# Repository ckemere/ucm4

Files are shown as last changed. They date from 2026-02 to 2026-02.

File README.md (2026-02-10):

# CM4-uSAW

Raspberry Pi Compute Module 4 micro carrier board with a multimodal Sensor Array and Wireless (uSAW) battery operation.

# Features

- Dual-camera inputs
- 9-axis IMU
- Stereo microphones
- GNSS module header (ZED GNSS)
- Stemma/QUIIC connector
- Power management
  - Battery charging & discharging
  - Fuel gauge
  - USB-C or L-ion power source
- SD card carrier
- UART Extension pins
- support for both Lite and eMMC variants of CM4
- USB C for power and USB 2.0 data transfer
- USB-OTG support

# Table of contents

1. [Sensors](sensors.md)

# License

This work is licensed under a [Creative Commons Attribution 4.0 International License][cc-by].

You can use it for anything as long as you preserve license file and author information in source distribution and authorship information on PCB. Derived work should mention original author in same locations as this repository.

[][cc-by]

[cc-by]: http://creativecommons.org/licenses/by/4.0/
[cc-by-image]: https://i.creativecommons.org/l/by/4.0/88x31.png

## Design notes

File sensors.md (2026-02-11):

## Cameras
Dual camera inputs on cam1 and cam0 lines.

### config.txt example:
# Disable auto-detect if you are forcing manual overlays
camera_auto_detect=0

# Define camera on Port 0
dtoverlay=imx708,cam0
# Define camera on Port 1
dtoverlay=imx708,cam1

## Stereo Microphone
Dual/stereo audio inputs on left and right edges of board.
MMICT390200012, converted from PDM to PCM.

### config.txt example:
dtoverlay=googlevoicehat-soundcard

## IMU
Bosh BNO055 9 axis IMU
UART channel 5

### config.txt example:
dtoverlay=uart5

## Fuel Gauge
MAX17048G+ smart battery fuel gauge.

# Enable I2C-3 for Fuel Gauge
dtoverlay=i2c3,pins_2_3

## GPS

### config.txt example:
dtoverlay=uart4

GPS UART4 connection seems to interfere with booting.

Fix:

Edit
/boot/firmware/cmdline.txt

The Edit:

    Find: A section of text looking like console=serial0,115200 (or console=ttyAMA0,115200).

    Action: Delete that specific section.

    Keep: Everything else (like root=..., console=tty1, fsck...).

Ensure cmdline.txt remains one single line of text. Do not add line breaks or newlines.

## All required configs (untested)

camera_auto_detect=0
dtoverlay=imx708,cam0
dtoverlay=imx708,cam1
dtoverlay=googlevoicehat-soundcard
dtoverlay=uart5
dtoverlay=i2c3,pins_2_3

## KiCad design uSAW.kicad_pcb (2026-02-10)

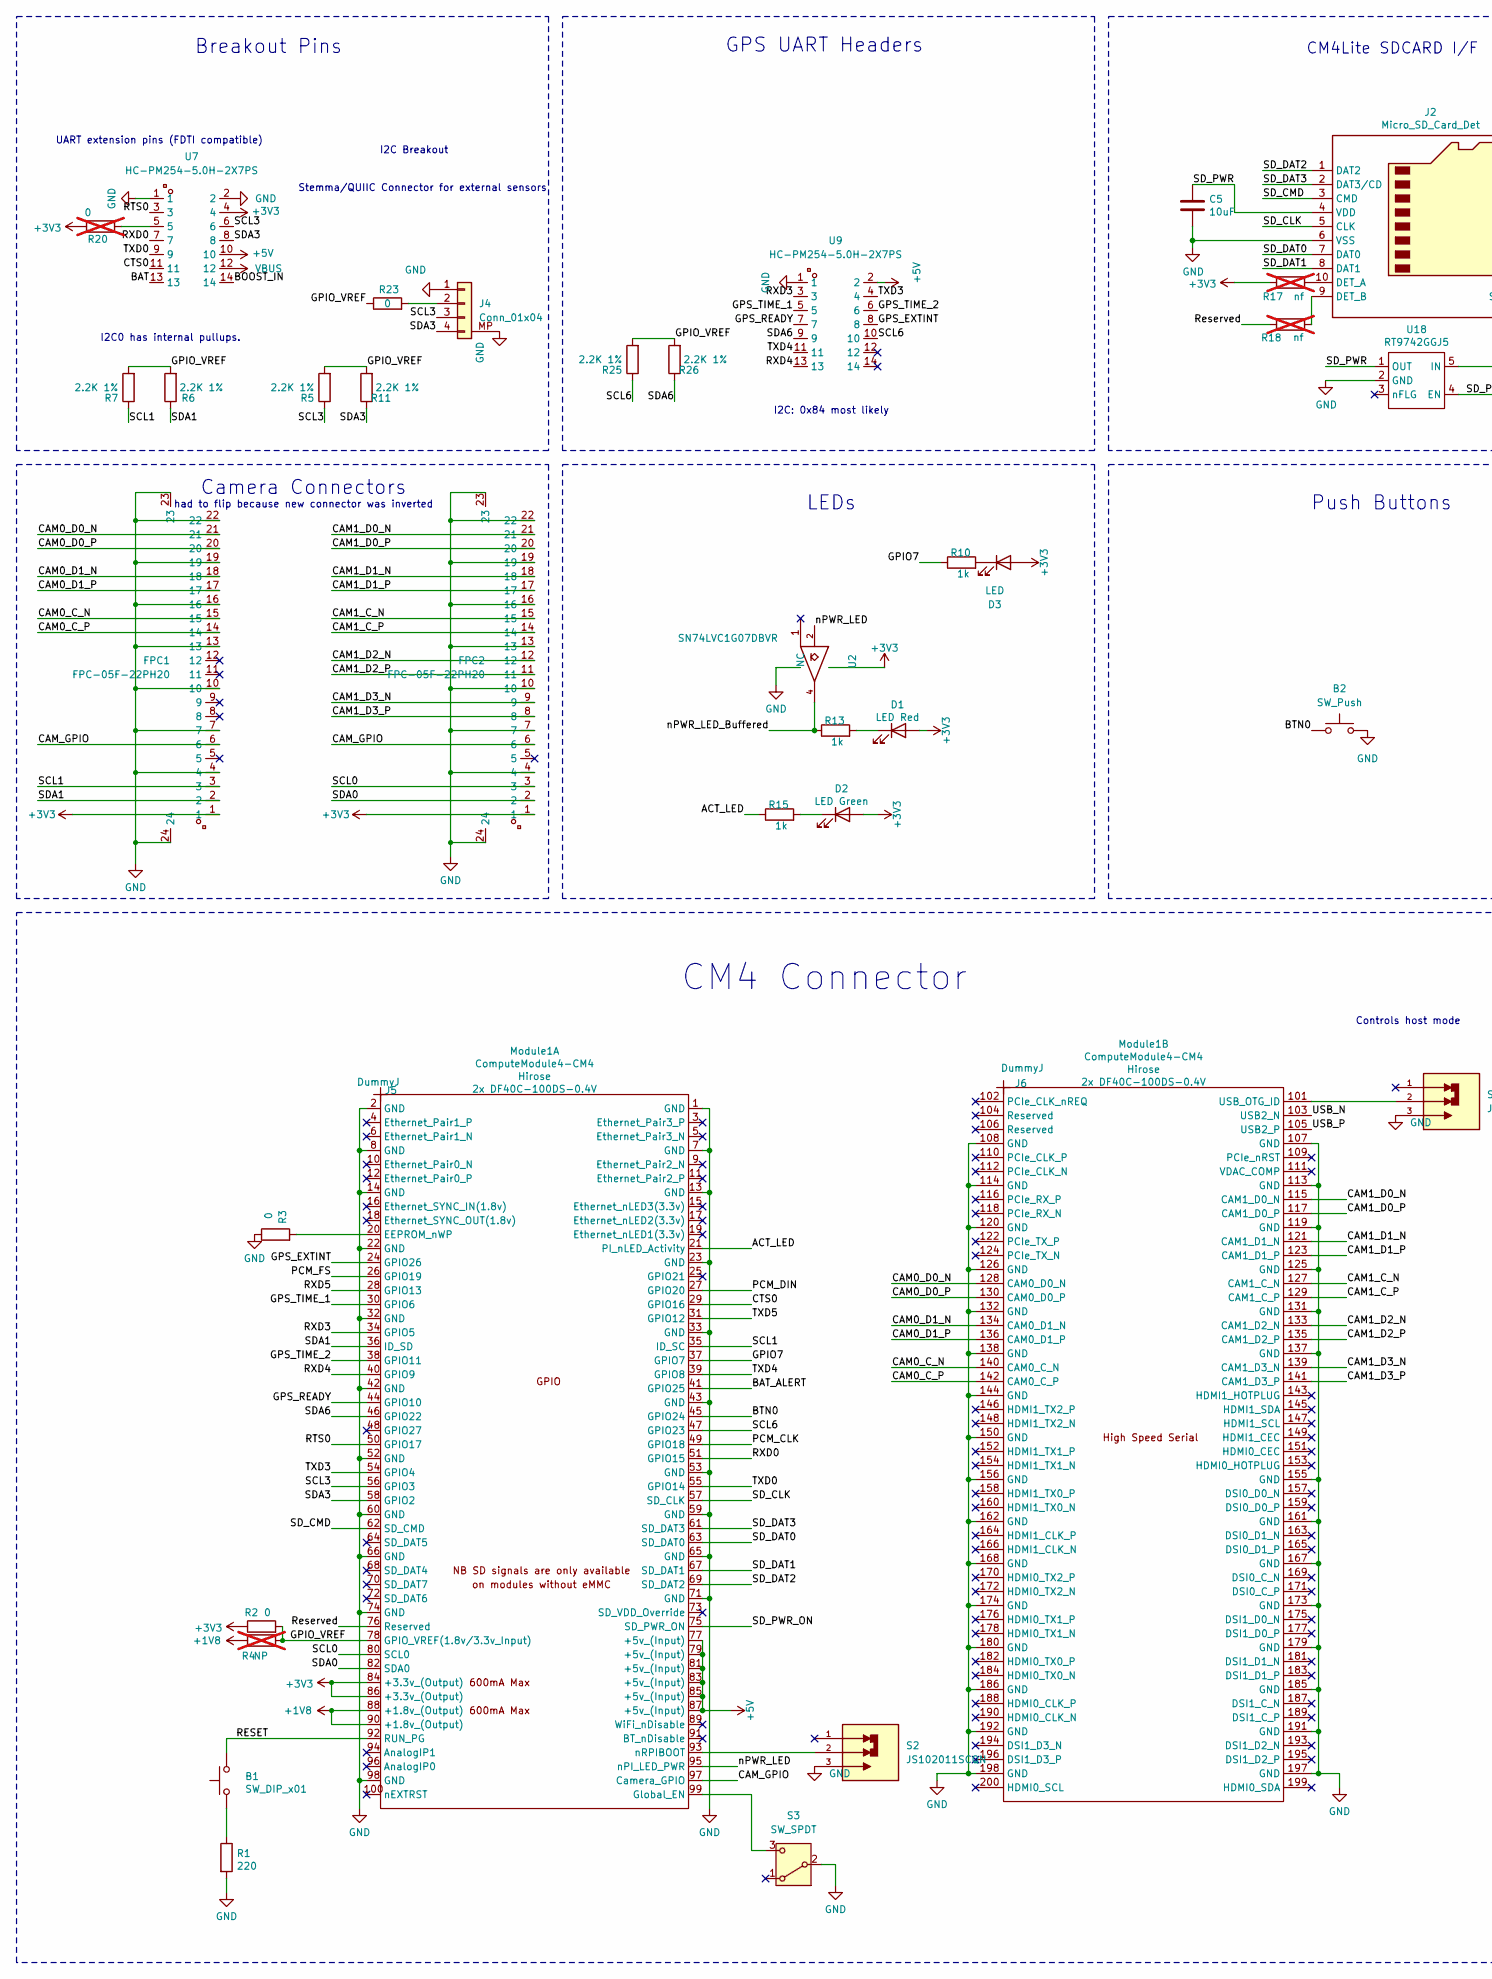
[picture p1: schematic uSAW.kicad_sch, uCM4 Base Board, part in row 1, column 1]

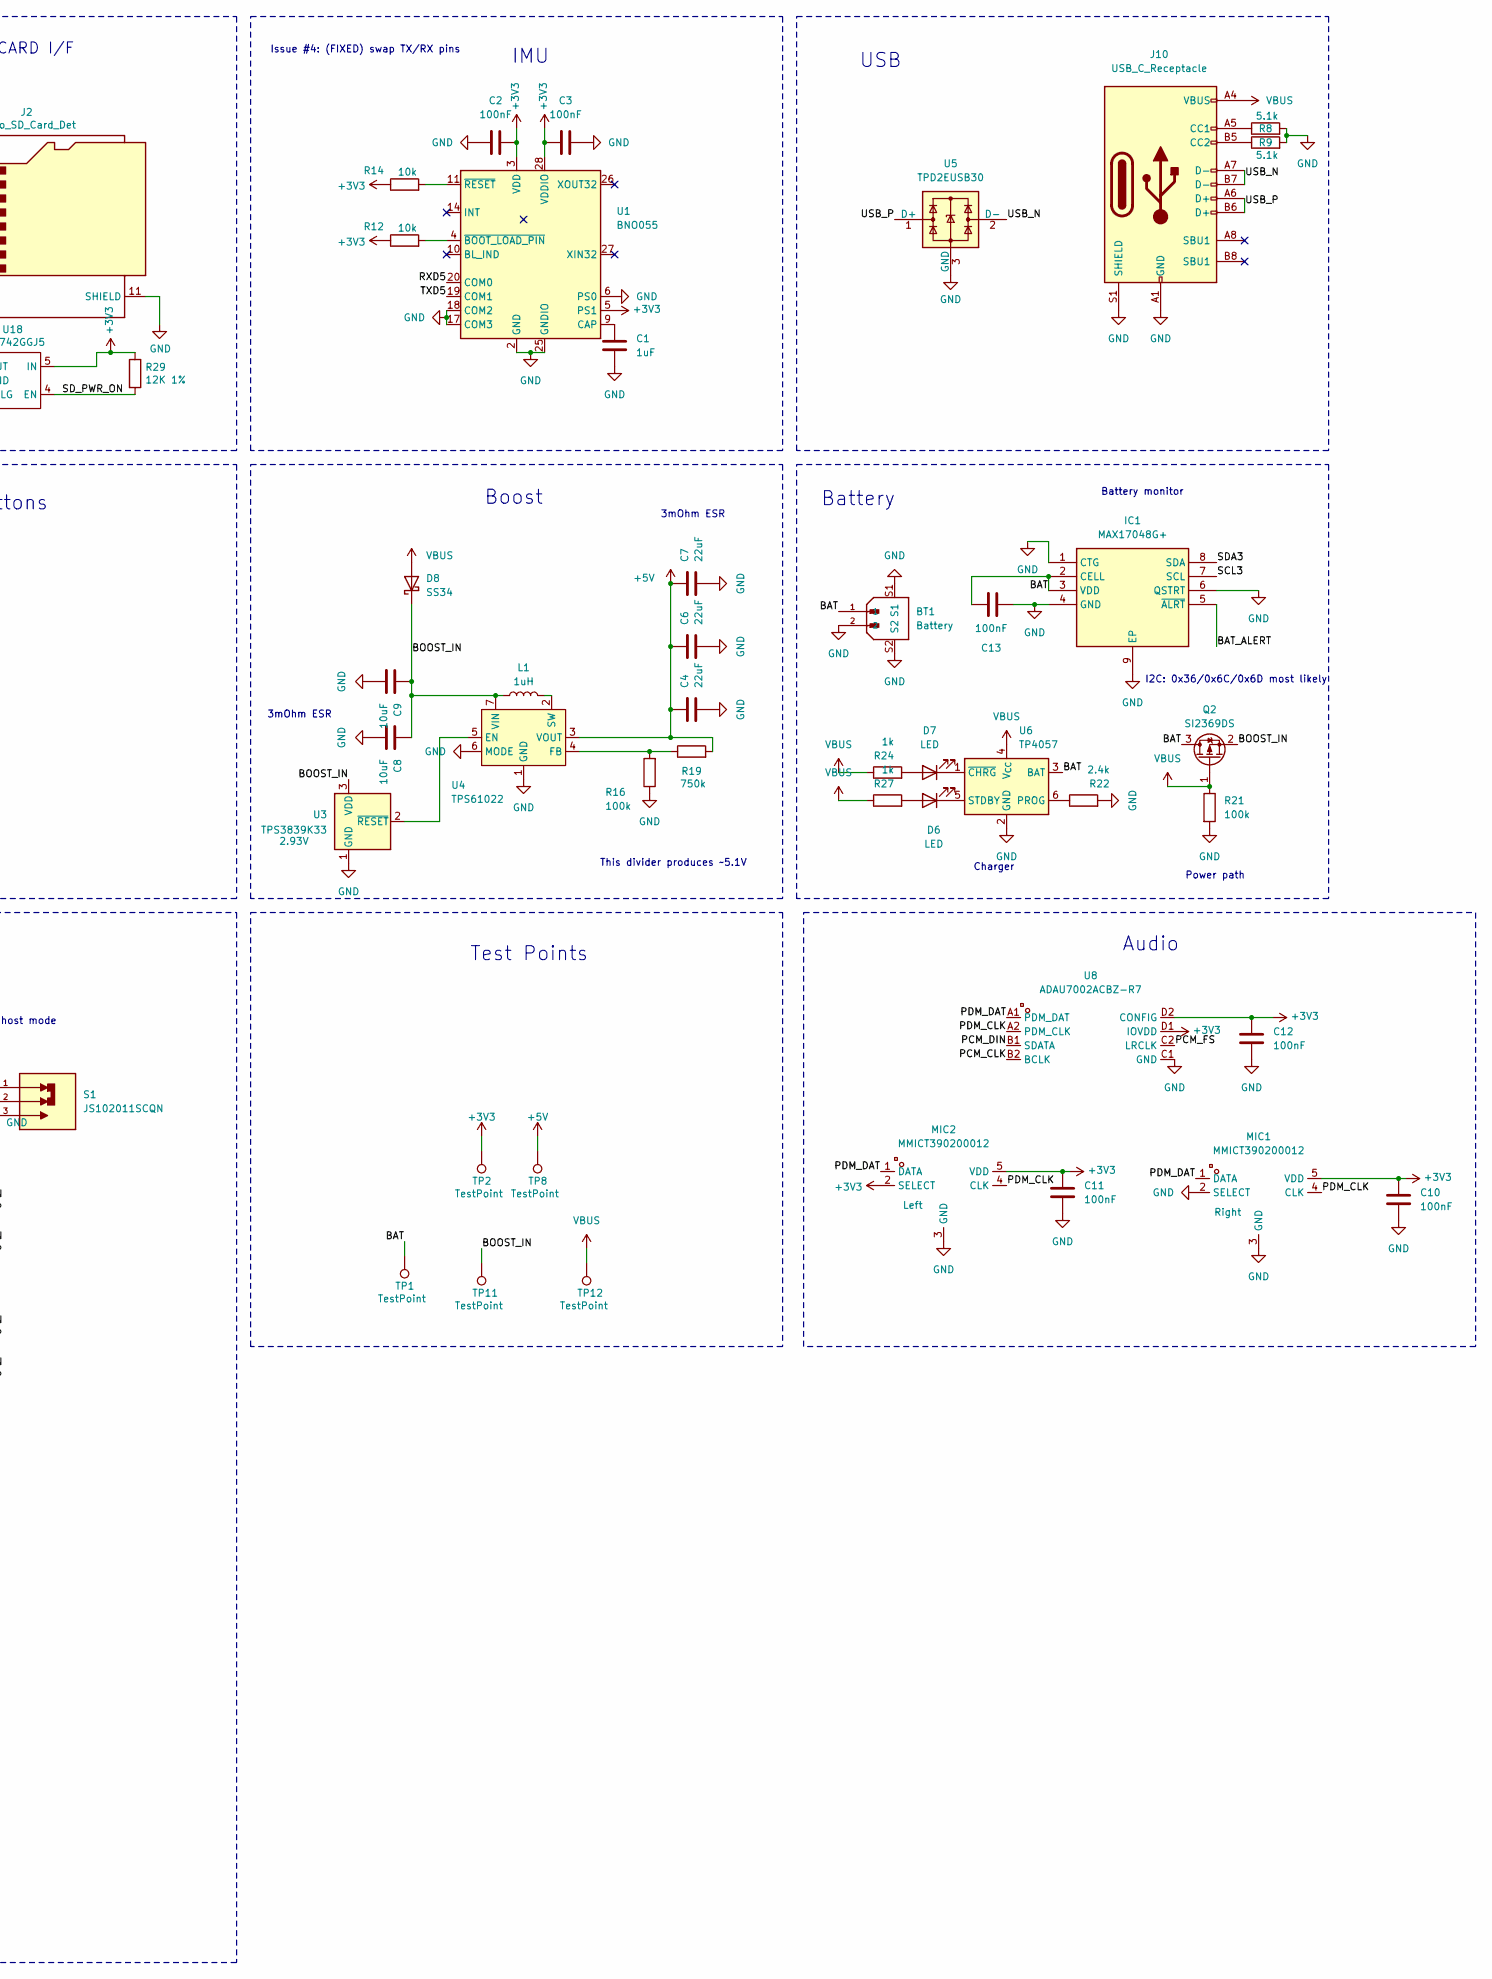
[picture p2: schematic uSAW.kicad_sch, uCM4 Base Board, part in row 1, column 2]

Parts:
B1: SW_DIP_x01; PTS840_PM_SMTR_LFS; LCSC Part # C221907
B2: SW_Push; PTS840_PM_SMTR_LFS; LCSC Part # C221907
BT1: Battery; JST_B2B-PH-SM4-TB; PARTREV N/A; LCSC Part # C2763702
C1: 1uF; C_0402_1005Metric; LCSC Part # C14445
C2, C3, C10, C11, C12, C13: 100nF; C_0402_1005Metric; LCSC Part # C1525
C4, C6, C7: 22uF; C_1206_3216Metric; LCSC Part # C12891
C5: 10uF; C_0603_1608Metric; Part Description 10uF 10% 10V Ceramic Capacitor X7R 0805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; LCSC Part # C19702
C8, C9: 10uF; C_0603_1608Metric; LCSC Part # C19702
D1: LED Red; LED_0402_1005Metric; LCSC Part # C264407
D2: LED Green; LED_0402_1005Metric; LCSC Part # C5123485
D3, D6: LED; LED_0402_1005Metric; LCSC Part # C5123485
D7: LED; LED_0402_1005Metric; LCSC Part # C264407
D8: SS34; D_SMA; LCSC Part # C727059
FPC1, FPC2: FPC-05F-22PH20; FPC-SMD_22P-P0.50_FPC-05F-22PH20; LCSC Part C2856804
IC1: MAX17048G+; SON50P200X200X80-9N-D; Manufacturer_Part_Number MAX17048G+; Mouser Part Number 700-MAX17048G+
J2: Micro_SD_Card_Det; SDCARD_MOLEX_503398-1892; Part Description 9 (8 + 1) Position Card Connector micro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; LCSC Part # C428492
J4: Conn_01x04; JST_SH_BM04B-SRSS-TB_1x04-1MP_P1.00mm_Vertical; LCSC Part # C160390
J5, J6: DummyJ; LCSC Part # C597931
J10: USB_C_Receptacle; USB_C_Receptacle_GCT_USB4105-xx-A_16P_TopMnt_Horizontal; LCSC C5184243
L1: 1uH; XAL7030102MEC; Part# XAL7030-102MEC; LCSC Part # C19191626
MIC1, MIC2: MMICT390200012; MIC-SMD_5P-L3.5-W2.7-TL_MMICT390200012; LCSC Part C3171752
Module1: ComputeModule4-CM4; Raspberry-Pi-4-Compute-Module; LCSC Part # C597931
Q2: SI2369DS; SOT-23; LCSC Part # C41348108
R1: 220; R_0603_1608Metric_Pad0.98x0.95mm_HandSolder; LCSC Part # C22962
R2, R3, R23: 0; R_0402_1005Metric; LCSC Part # C106231
R4: NP; R_0402_1005Metric; LCSC Part # C106231; not fitted
R5, R6, R7, R11, R25, R26: 2.2K 1%; R_0402_1005Metric; Part Description Resistor 2.2K M1005 1% 63mW; LCSC Part # C60488
R8, R9: 5.1k; R_0402_1005Metric; LCSC Part # C25905
R10, R13, R15, R24, R27: 1k; R_0402_1005Metric; LCSC Part # C106235
R12, R14: 10k; R_0402_1005Metric; LCSC Part # C60490
R16, R21: 100k; R_0402_1005Metric; LCSC Part # C852472
R17, R18: nf; R_0402_1005Metric; Part Description Resistor 1K M1005 1% 63mW; not fitted
R19: 750k; R_0402_1005Metric; LCSC Part # C2909381
R20: 0; R_0402_1005Metric; LCSC Part # C21189; not fitted
R22: 2.4k; R_0402_1005Metric; LCSC Part # C25882
R29: 12K 1%; R_0402_1005Metric; Part Description Resistor 12K M1005 1% 63mW; LCSC Part # C25752
S1, S2: JS102011SCQN; SW_JS102011SCQN; PARTREV 8 Oct 21; LCSC Part # C221661
S3: SW_SPDT; SW_SPDT_PCM12; LCSC Part # C221841
TP1, TP2, TP8, TP11, TP12: TestPoint; TestPoint_Pad_D1.0mm
U1: BNO055; LGA-28_5.2x3.8mm_P0.5mm; LCSC Part # C93216
U2: SN74LVC1G07DBVR; SOT-23-5_HandSoldering; LCSC Part # C7829
U3: TPS3839DBZ; SOT-23; Threshold voltage 2.93V; Part_Code TPS3839K33; LCSC Part # C96333
U4: TPS61022; Texas_RWU0007A_VQFN-7_2x2mm_P0.5mm; LCSC Part # C915088
U5: TPD2EUSB30; Texas_DRT-3; LCSC Part # C3040102
U6: TP4057; TSOT-23-6; LCSC Part # C725791
U7, U9: HC-PM254-5.0H-2X7PS; HDR-SMD_14P-P2.54-V-F-R2-C7-LS7.4; LCSC Part # C42163135
U8: ADAU7002ACBZ-R7; WLCSP-8_L1.6-W0.8-R2-C4-P0.40-TL; LCSC Part C481886
U18: RT9742GGJ5; SOT-23-5; Part Description Power Switch/Driver 1:1 N-Channel 1A TS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; LCSC Part # C250547

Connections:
+1V8: Module1.88 (+1.8v_(Output)), Module1.90 (+1.8v_(Output)), R4.1
+3V3: C2.2, C3.2, C10.1, C11.1, C12.1, D1.2 (A), D2.2 (A), D3.2 (A), FPC1.1, FPC2.1, MIC1.5 (VDD), MIC2.2 (SELECT), MIC2.5 (VDD), Module1.84 (+3.3v_(Output)), Module1.86 (+3.3v_(Output)), R2.1, R12.1, R14.1, R17.1, R20.1, R29.1, TP2.1, U1.3 (VDD), U1.5 (PS1), U1.28 (VDDIO), U2.5 (VCC), U7.4, U8.D1 (IOVDD), U8.D2 (CONFIG), U18.5 (IN)
+5V: C4.1, C6.1, C7.1, Module1.77 (+5v_(Input)), Module1.79 (+5v_(Input)), Module1.81 (+5v_(Input)), Module1.83 (+5v_(Input)), Module1.85 (+5v_(Input)), Module1.87 (+5v_(Input)), R19.2, TP8.1, U4.3 (VOUT), U7.10, U9.2
/ACT_LED: Module1.21 (PI_nLED_Activity), R15.1
/BAT: BT1.1, C13.1, IC1.2 (CELL), IC1.3 (VDD), Q2.3 (D), TP1.1, U6.3 (BAT), U7.13
/BAT_ALERT: IC1.5 (~ALRT), Module1.41 (GPIO25)
/BOOST_IN: C8.1, C9.1, D8.1 (K), L1.1, Q2.2 (S), TP11.1, U3.3 (VDD), U4.7 (VIN), U7.14
/BTN0: B2.1, Module1.45 (GPIO24)
/CAM0_C_N: FPC1.15, Module1.140 (CAM0_C_N)
/CAM0_C_P: FPC1.14, Module1.142 (CAM0_C_P)
/CAM0_D0_N: FPC1.21, Module1.128 (CAM0_D0_N)
/CAM0_D0_P: FPC1.20, Module1.130 (CAM0_D0_P)
/CAM0_D1_N: FPC1.18, Module1.134 (CAM0_D1_N)
/CAM0_D1_P: FPC1.17, Module1.136 (CAM0_D1_P)
/CAM1_C_N: FPC2.15, Module1.127 (CAM1_C_N)
/CAM1_C_P: FPC2.14, Module1.129 (CAM1_C_P)
/CAM1_D0_N: FPC2.21, Module1.115 (CAM1_D0_N)
/CAM1_D0_P: FPC2.20, Module1.117 (CAM1_D0_P)
/CAM1_D1_N: FPC2.18, Module1.121 (CAM1_D1_N)
/CAM1_D1_P: FPC2.17, Module1.123 (CAM1_D1_P)
/CAM1_D2_N: FPC2.12, Module1.133 (CAM1_D2_N)
/CAM1_D2_P: FPC2.11, Module1.135 (CAM1_D2_P)
/CAM1_D3_N: FPC2.9, Module1.139 (CAM1_D3_N)
/CAM1_D3_P: FPC2.8, Module1.141 (CAM1_D3_P)
/CAM_GPIO: FPC1.6, FPC2.6, Module1.97 (Camera_GPIO)
/CTS0: Module1.29 (GPIO16), U7.11
/GPIO7: Module1.37 (GPIO7), R10.1
/GPIO_VREF: Module1.78 (GPIO_VREF(1.8v/3.3v_Input)), R2.2, R4.2, R5.2, R6.2, R7.2, R11.2, R23.1, R25.2, R26.2
/GPS_EXTINT: Module1.24 (GPIO26), U9.8
/GPS_READY: Module1.44 (GPIO10), U9.7
/GPS_TIME_1: Module1.30 (GPIO6), U9.5
/GPS_TIME_2: Module1.38 (GPIO11), U9.6
/PCM_CLK: Module1.49 (GPIO18), U8.B2 (BCLK)
/PCM_DIN: Module1.27 (GPIO20), U8.B1 (SDATA)
/PCM_FS: Module1.26 (GPIO19), U8.C2 (LRCLK)
/PDM_CLK: MIC1.4 (CLK), MIC2.4 (CLK), U8.A2 (PDM_CLK)
/PDM_DAT: MIC1.1 (DATA), MIC2.1 (DATA), U8.A1 (PDM_DAT)
/RESET: B1.2, Module1.92 (RUN_PG)
/RTS0: Module1.50 (GPIO17), U7.3
/RXD0: Module1.51 (GPIO15), U7.7
/RXD3: Module1.34 (GPIO5), U9.3
/RXD4: Module1.40 (GPIO9), U9.13
/RXD5: Module1.28 (GPIO13), U1.20 (COM0)
/Reserved: Module1.76 (Reserved), R18.1
/SCL0: FPC2.3, Module1.80 (SCL0)
/SCL1: FPC1.3, Module1.35 (ID_SC), R7.1
/SCL3: IC1.7 (SCL), J4.3, Module1.56 (GPIO3), R5.1, U7.6
/SCL6: Module1.47 (GPIO23), R25.1, U9.10
/SDA0: FPC2.2, Module1.82 (SDA0)
/SDA1: FPC1.2, Module1.36 (ID_SD), R6.1
/SDA3: IC1.8 (SDA), J4.4, Module1.58 (GPIO2), R11.1, U7.8
/SDA6: Module1.46 (GPIO22), R26.1, U9.9
/SD_CLK: J2.5 (CLK), Module1.57 (SD_CLK)
/SD_CMD: J2.3 (CMD), Module1.62 (SD_CMD)
/SD_DAT0: J2.7 (DAT0), Module1.63 (SD_DAT0)
/SD_DAT1: J2.8 (DAT1), Module1.67 (SD_DAT1)
/SD_DAT2: J2.1 (DAT2), Module1.69 (SD_DAT2)
/SD_DAT3: J2.2 (DAT3/CD), Module1.61 (SD_DAT3)
/SD_PWR: C5.1, J2.4 (VDD), U18.1 (OUT)
/SD_PWR_ON: Module1.75 (SD_PWR_ON), R29.2, U18.4 (EN)
/TXD0: Module1.55 (GPIO14), U7.9
/TXD3: Module1.54 (GPIO4), U9.4
/TXD4: Module1.39 (GPIO8), U9.11
/TXD5: Module1.31 (GPIO12), U1.19 (COM1)
/USB_N: J10.A7 (D-), J10.B7 (D-), Module1.103 (USB2_N), U5.2 (D-)
/USB_P: J10.A6 (D+), J10.B6 (D+), Module1.105 (USB2_P), U5.1 (D+)
/nPWR_LED: Module1.95 (nPI_LED_PWR), U2.2
/nPWR_LED_Buffered: R13.1, U2.4
GND: B2.2, BT1.2, BT1.S1, BT1.S2, C1.1, C2.1, C3.1, C4.2, C5.2, C6.2, C7.2, C8.2, C9.2, C10.2, C11.2, C12.2, C13.2, FPC1.4, FPC1.7, FPC1.10, FPC1.13, FPC1.16, FPC1.19, FPC1.22, FPC1.23, FPC1.24, FPC2.4, FPC2.7, FPC2.10, FPC2.13, FPC2.16, FPC2.19, FPC2.22, FPC2.23, FPC2.24, IC1.1 (CTG), IC1.4 (GND), IC1.6 (QSTRT), IC1.9 (EP), J2.6 (VSS), J2.11 (SHIELD), J4.1, J4.MP, J10.A1 (GND), J10.A12 (GND), J10.B1 (GND), J10.B12 (GND), J10.S1 (SHIELD), MIC1.2 (SELECT), MIC1.3 (GND), MIC2.3 (GND), Module1.1 (GND), Module1.2 (GND), Module1.7 (GND), Module1.8 (GND), Module1.13 (GND), Module1.14 (GND), Module1.22 (GND), Module1.23 (GND), Module1.32 (GND), Module1.33 (GND), Module1.42 (GND), Module1.43 (GND), Module1.52 (GND), Module1.53 (GND), Module1.59 (GND), Module1.60 (GND), Module1.65 (GND), Module1.66 (GND), Module1.71 (GND), Module1.74 (GND), Module1.98 (GND), Module1.107 (GND), Module1.108 (GND), Module1.113 (GND), Module1.114 (GND), Module1.119 (GND), Module1.120 (GND), Module1.125 (GND), Module1.126 (GND), Module1.131 (GND), Module1.132 (GND), Module1.137 (GND), Module1.138 (GND), Module1.144 (GND), Module1.150 (GND), Module1.155 (GND), Module1.156 (GND), Module1.161 (GND), Module1.162 (GND), Module1.167 (GND), Module1.168 (GND), Module1.173 (GND), Module1.174 (GND), Module1.179 (GND), Module1.180 (GND), Module1.185 (GND), Module1.186 (GND), Module1.191 (GND), Module1.192 (GND), Module1.197 (GND), Module1.198 (GND), R1.2, R3.1, R8.2, R9.2, R16.1, R21.2, R22.2, S1.3, S2.3, S3.2 (B), U1.2 (GND), U1.6 (PS0), U1.17 (COM3), U1.18 (COM2), U1.25 (GNDIO), U2.3 (GND), U3.1 (GND), U4.1 (GND), U4.6 (MODE), U5.3 (GND), U6.2 (GND), U7.1, U7.2, U8.C1 (GND), U9.1, U18.2 (GND)
unnamed: B1.1, R1.1
unnamed: D1.1 (K), R13.2
unnamed: D2.1 (K), R15.2
unnamed: D3.1 (K), R10.2
unnamed: D6.2 (A), R27.2
unnamed: D6.1 (K), U6.5 (STDBY)
unnamed: D7.2 (A), R24.2
unnamed: D7.1 (K), U6.1 (~CHRG)
unnamed: J2.10 (DET_A), R17.2
unnamed: J2.9 (DET_B), R18.2
unnamed: J4.2, R23.2
unnamed: J10.A5 (CC1), R8.1
unnamed: J10.B5 (CC2), R9.1
unnamed: Module1.20 (EEPROM_nWP), R3.2
unnamed: Module1.99 (Global_EN), S3.3 (C)
unnamed: Module1.93 (nRPIBOOT), S2.2
unnamed: Module1.101 (USB_OTG_ID), S1.2
unnamed: R20.2, U7.5
unnamed: C1.2, U1.9 (CAP)
unnamed: R12.2, U1.4 (~BOOT_LOAD_PIN)
unnamed: R14.2, U1.11 (~RESET)
unnamed: U3.2 (~RESET), U4.5 (EN)
unnamed: R16.2, R19.1, U4.4 (FB)
unnamed: L1.2, U4.2 (SW)
unnamed: R22.1, U6.6 (PROG)
VBUS: D8.2 (A), J10.A4 (VBUS), J10.A9 (VBUS), J10.B4 (VBUS), J10.B9 (VBUS), Q2.1 (G), R21.1, R24.1, R27.1, TP12.1, U6.4 (V_{CC}), U7.12

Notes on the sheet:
CM4 Connector
Battery monitor
3mOhm ESR
Test Points
Push Buttons
I2C: 0x84 most likely
Battery
CM4Lite SDCARD I/F
Controls host mode
had to flip because new connector was inverted
GPS UART Headers
This divider produces ~5.1V
UART extension pins (FDTI compatible)
IMU
USB
I2C Breakout
LEDs
Audio
Boost
Power path
Charger
Stemma/QUIIC Connector for external sensors
Issue #4: (FIXED) swap TX/RX pins
Camera Connectors
I2C: 0x36/0x6C/0x6D most likely
Breakout Pins
I2C0 has internal pullups.

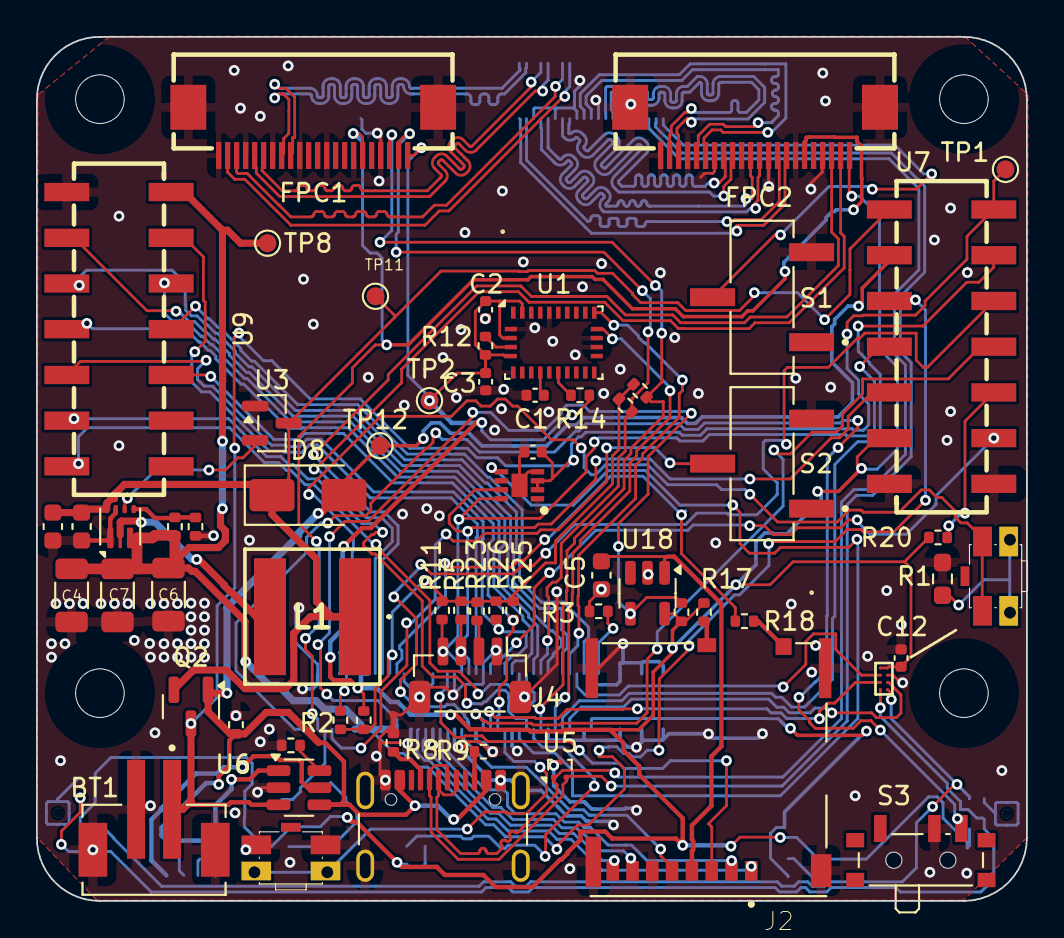
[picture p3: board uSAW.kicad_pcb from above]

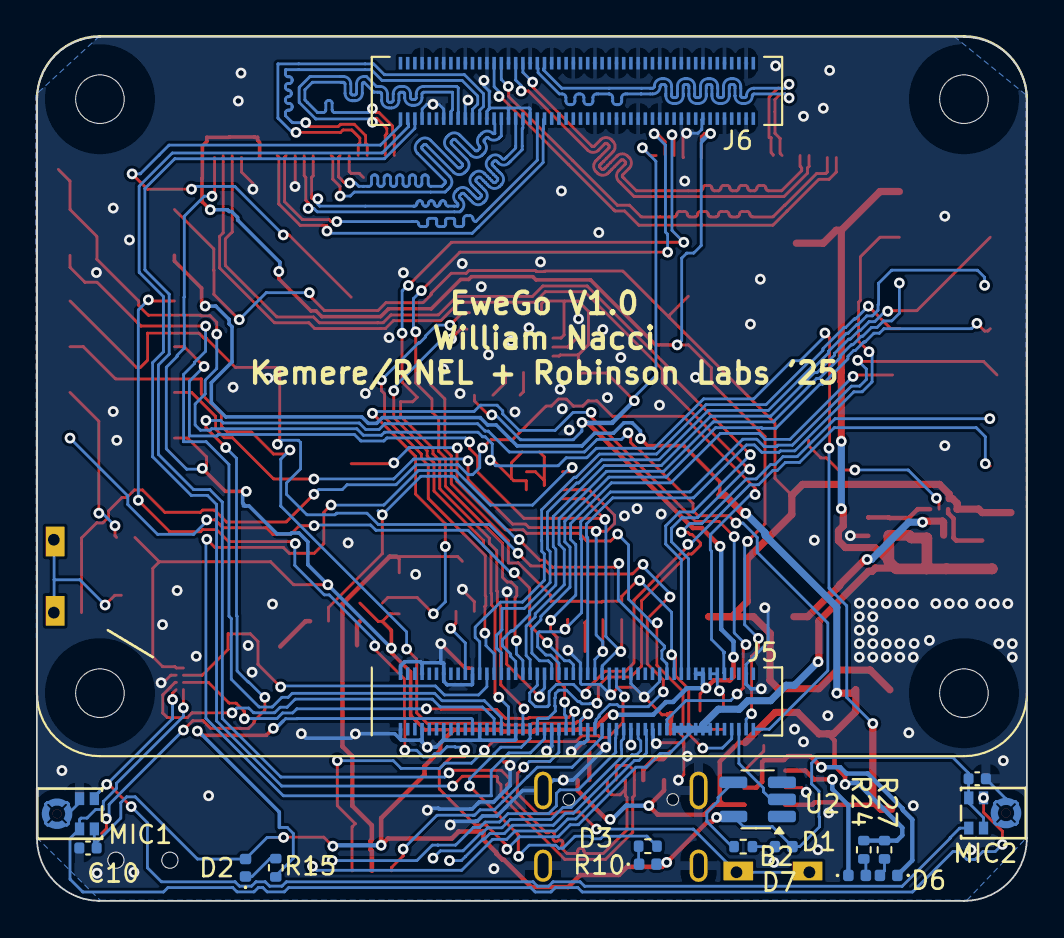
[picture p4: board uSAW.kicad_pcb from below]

Board: 2 copper layers, 55.0 x 48.0 mm, 81 parts (18 on the bottom side), 95 nets.

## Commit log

2025-12-04 Editing models & etc. (oops?) Importing camera connectors.
    [uCM4.kicad_pcb, uCM4.kicad_sch]
2025-12-04 Removed ethernet connector
    [uCM4.kicad_pcb, uCM4.kicad_sch]
2025-12-04 Cameras added in sch.
    [uCM4.kicad_pcb, uCM4.kicad_sch]
2025-12-04 Added text
    [uCM4.kicad_sch]
2025-12-05 Adding different camera connectors
    [uCM4.kicad_sch]
2025-12-05 Adding vertical cam connectors
2025-12-07 Revert "Added text"
    This reverts commit 62975cc76e4f780cb44087bac7d1ba26b0b1c88f.
    [uCM4.kicad_sch]
2025-12-07 Reapply "Added text"
    This reverts commit ba47ba2ab880adebf2a51512258938aba623be2e.
    [uCM4.kicad_sch]
2025-12-07 Revert "Adding vertical cam connectors"
    This reverts commit 5f1061bc0e5e73f1cfbd759f8bf3abef7a074a53.
2025-12-07 Revert "Adding different camera connectors"
    This reverts commit 13c594ec966e128ca79b7e90b630a66479b00dc6.
    [uCM4.kicad_sch]
2025-12-07 Adding UART pins and changing connectors.
    [uCM4.kicad_sch]
2025-12-07 Added GPS UART to sch
    [uCM4.kicad_sch]
2025-12-07 Added IMU
    [uCM4.kicad_sch]
2025-12-07 Added battery boost, reorganized schematic.
    [uCM4.kicad_pcb, uCM4.kicad_sch]
2025-12-07 Adding 3d models and arranging board
    [uCM4.kicad_pcb, uCM4.kicad_sch]
2025-12-07 PCB Arrangement
    [uCM4.kicad_pcb]
2025-12-07 Added environmental sensor.
    [uCM4.kicad_pcb, uCM4.kicad_sch]
2025-12-08 Changing connectors and arranging PCB.
    [uCM4.kicad_pcb, uCM4.kicad_sch]
2025-12-08 Changing models & some initial routing
    [uCM4.kicad_pcb, uCM4.kicad_sch]
2025-12-09 Added STEMMA connector and some comments
    [uCM4.kicad_sch]
2025-12-09 Added fuel gauge + USB C + some other things
    [uCM4.kicad_sch]
2025-12-09 Adding battery charging circuitry.
    [uCM4.kicad_sch]
2025-12-09 Removing onboard environmental sensor.
    [uCM4.kicad_sch]
2025-12-10 Changed some parts and hopeful final PCB arrangement.
    [uCM4.kicad_pcb, uCM4.kicad_sch]
2025-12-11 Moving LEDs
    [uCM4.kicad_pcb]
2025-12-11 Changed resistors to 0402
    [uCM4.kicad_sch]
2025-12-11 Changed capacitor sizes
    [uCM4.kicad_sch]
2025-12-11 Updated USB-C connector to be simpler.
    [uCM4.kicad_pcb, uCM4.kicad_sch]
2025-12-11 Arranging and changing switches.
    [uCM4.kicad_pcb, uCM4.kicad_sch]
2025-12-12 Correcting symbols and routing progress.
    [uCM4.kicad_pcb, uCM4.kicad_sch]
2025-12-12 Updating LCSC numbers.
    [uCM4.kicad_pcb, uCM4.kicad_sch]
2025-12-12 Minor changes
    [uCM4.kicad_pcb]
2025-12-12 Tuning differential traces and changing some footprints
    [uCM4.kicad_pcb, uCM4.kicad_sch]
2025-12-12 Finalized LCSC selections
    [uCM4.kicad_sch]
2025-12-13 Prepping for production.
    [uCM4.kicad_pcb, uCM4.kicad_sch]
2025-12-13 Updated comments.
    [uCM4.kicad_sch]
2026-01-16 Adding github issues. Almost completed in schematic.
    [uCM4.kicad_sch]
2026-01-16 Fixed switches.
    [uCM4.kicad_sch]
2026-01-16 Board fixes. Fixed PMU (via UVLO via voltage monitor for buck) changed I2C lines, FET replacment, etc. Issues listed as 'Issue' comments on schematic.
    [uCM4.kicad_sch]
2026-01-17 Adding new parts to the project, fixing a number of issues on board, adding audio interface.
    [uCM4.kicad_sch, uCM4.step]
2026-01-17 Added new camera connectors. (Had to flip the symbol to match up hirose connection order)
    [uCM4.kicad_pcb, uCM4.kicad_sch]
2026-01-17 Routing in progress
    [uCM4.kicad_pcb, uCM4.kicad_sch]
2026-01-17 Routed and should be ready to order
    [uCM4.kicad_pcb, uCM4.kicad_sch]
2026-01-18 Routed first camera (with proper length matching this time)
    [uCM4.kicad_pcb, uCM4.kicad_sch]
2026-01-18 Second camera routed (with proper trace lengths this time!)
    [uCM4.kicad_pcb]
2026-01-18 DRC checked.
    [uCM4.kicad_pcb]
2026-01-18 Switched camera I2Cs to match official RPi documentation.
    [uCM4.kicad_pcb, uCM4.kicad_sch]
2026-01-18 Cleared issue messages.
    [uCM4.kicad_sch]
2026-01-18 Production ready files.
    [uCM4.kicad_pcb, uCM4.kicad_sch]
2026-02-06 Added voltage label to monitor.
    [uCM4.kicad_sch]
2026-02-10 Moved component files to subdirectory and fixed/improved some 3d models
    [uCM4.kicad_pcb, uCM4.step]
2026-02-10 Footprint change
    [uCM4.kicad_sch]
2026-02-10 Renamed project.
    [uSAW.kicad_pcb, uSAW.kicad_sch]
2026-02-11 More detail on sensor configs.
